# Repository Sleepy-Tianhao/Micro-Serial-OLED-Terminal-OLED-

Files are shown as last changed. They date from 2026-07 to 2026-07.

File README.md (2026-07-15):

# Micro Serial OLED Terminal (MSOT)  
> 嵌入式串口数据实时终端显示器 – 基于 Atmega328p + 0.96" OLED  

        

**Micro Serial OLED Terminal** 基于 Atmega328p 打造的轻量级串口数据显示终端，在 0.96 英寸屏幕上实时滚动显示串口ASCII 文本。支持一键 **暂停/恢复** 屏幕刷新，便于仔细查看历史数据，同时后台继续接收串口信息，恢复时即时补全。适用于嵌入式调试、传感器监控，**快速 & 便捷** 查看串口信息

---
# ⚙️ 特色功能
1. 配备有typec接口, **支持C to C数据线供电**, 支持由终端设备为调试设备供电,免去供电烦恼
2. 同时支持从调试设备取电, 即插即用
3. 支持**一键暂停**, 快速锁定内容
4. **跨平台换行兼容** – 支持 Windows (`\r\n`)、Linux (`\n`)、Mac (`\r`) 的换行风格。
5. **实时滚动显示** – 自动处理换行符（`\n` / `\r` / `\r\n`），实现平滑滚动，无撕裂或闪烁。

## 快速开始

>有关制作及其注意事项请详见此[文档](build.md)

### 外设
| 接口 | 功能 |
| :--- | :--- |
| USB-C | 仅供电, 兼容 C to C 数据线* |
| 4pin 排针 | 供电, 串口信号输入 |
| 拨轮 | 上拨向上翻页, 中键翻转刷新状态, 下拨向下翻页 |
| 蜂鸣器** | 按键提示 |

> *注: 须焊接R5 R6设为下拉以兼容 C to C数据线
  **注: 对应电路元件封装较小(0402封装), 不便于焊接, 此项为可选项

### 接线
| 4pin 排针(屏幕面从左到右) | 对外调试设备 |
| :--- | :--- |
| GND | GND |
| TXD | RXD |
| RXD | TXD |
| VCC | VCC / 5V |

## 🕹️ 使用说明  

### 基本操作  

| 操作 | 效果 |
| :--- | :--- |
| 串口发送文本（如 `Hello World\n`） | OLED 上滚动显示该行 |
| 发送超长文本（>21 字符） | 自动在 21 字符处换行 |
| 发送空行（单独 `\n`） | 产生一个空白行，用于间隔 |
| 按下中键 | 屏幕冻结，但串口继续接收 |
| 再次按下中键 | 屏幕立即补全所有新内容 |

### 软件环境
- **Arduino IDE** (≥1.8.13) 或 **PlatformIO**  
- 安装依赖库（通过 Arduino 库管理器）：  
  - `U8g2` by olikraus (≥2.28.10)  
  - `Adafruit BusIO`（U8g2 的依赖）

---

## 📦编译上传 
### 一. BootLoader烧录
1. 对于需 Arduino UNO / Nano 拆板的MCU可跳过此步骤, 移步至 **程序烧录** 步骤
2. 对于全新 Atmega328p 芯片: 
    1. 安装到编程座上, 或直接焊接至开发板上
    2. 使用AVRISP, 烧录BootLoader
       或使用另一块Arduino, 先上传Arduino ISP程序: *文件 --> 示例 --> ArduinoISP*, 然后按以下表格进行接线
    3. 点击 *工具 --> 编程器 --> Arduino as ISP (此项根据对应编程器选择, 此处以 Arduino as ISP 为例)*
    4. 点击 *烧录引导程序*

| 作为编程器的Arduino | 目标对象 |
| :--- | :--- |
| 13 | 13 |
| 12 | 12 |
| 11 | 11 |
| 10 | REST |
| GND | GND |
| VCC | VCC |

### 二. 程序烧录
>虽然PCB板已引出REST引脚, 但仍然建议先烧录程序, 再安装芯片到PCB板上
1. 下载位于src目录下的源码 `main.ino`。  
2. 在 Arduino IDE 中选择开发板 **Arduino Nano** 和对应串口。  
3. 点击 **上传**。  
4. 打开串口监视器（默认波特率 115200），发送任意文本，OLED 将立即滚动显示。

```shell
# 示例：发送 "Hello World\n"
# OLED 屏幕将显示该行，并自动换行滚动
```

---

## 开发指南

若你想在此基础上进行二次开发或定制，请遵循以下步骤：

```shell
git clone https://github.com/yourname/serial-oled-terminal.git
cd serial-oled-terminal/
# 使用 Arduino IDE 打开 main.ino，或使用 PlatformIO 打开项目文件夹
```

### 项目结构
```
├──PCB                       # PCB原始文件
├──BOM                       # 元件清单
├──Image                     # 示意图
├──Gerber                    # 制板文件
├──src
    └──  main.ino            # 主程序
├── README.md                # 本文件
└── LICENSE                  # MIT 许可证
```

### 核心代码模块
- **`processSerialData()`** – 非阻塞读取串口，解析 `\r`/`\n`，更新行缓冲区。  
- **`scrollUp()`** – 滚动显存数组（丢弃最旧行，为新行腾出空间）。  
- **`renderDisplay()`** – 使用 U8g2 全帧缓冲绘制并发送到 OLED。  
- **`handleButton()`** – 检测按钮下降沿，软件消抖，切换暂停状态。

## 🔧自定义配置
你可以在文件顶部修改以下宏定义以适应不同屏幕尺寸或硬件：

| 宏定义 | 默认值 | 说明 |
| :--- | :--- | :--- |
| `SCREEN_ROWS` | 6 | 显示行数（根据 OLED 高度和字体调整） |
| `SCREEN_COLS` / `MAX_LINE_LEN` | 21 | 每行字符数（根据 OLED 宽度和字体调整） |
| `BTN_PIN` | 2 | 按钮引脚号 |
| `DEBOUNCE_DELAY` | 50 | 消抖时间（毫秒） |

### 构建与测试
- 若更改了屏幕分辨率或字体，请同步调整 `SCREEN_ROWS` 和 `SCREEN_COLS`。  
- 编译时注意 RAM 占用（由于 ~硬件资源有限~ 个人能力不足, 当前已达94%）  
- 如需提升刷新速度，可在 `setup()` 中添加 `Wire.setClock(400000L);` 将 I2C 频率提至 400kHz。

### 配置参数

本项目提供了若干可调节的配置项，以适应不同硬件或偏好。

#### `SCREEN_ROWS`
- **类型**：`int`  
- **默认值**：`6`  
- **说明**：OLED 屏幕上显示的文字行数。根据屏幕高度和所选字体（当前为 6×10 像素）计算，例如 64 像素高度 / 10 像素行高 = 6 行。

#### `SCREEN_COLS`（同 `MAX_LINE_LEN`）
- **类型**：`int`  
- **默认值**：`21`  
- **说明**：每行最多容纳的字符数。根据屏幕宽度和字体宽度（6 像素）计算，128 / 6 ≈ 21。

#### `DEBOUNCE_DELAY`
- **类型**：`unsigned long`（毫秒）  
- **默认值**：`50`  
- **说明**：按钮消抖延时窗口。若按钮抖动较严重，可适当增大（如 100ms）。

#### 串口波特率
- **类型**：`long`  
- **默认值**：`115200`  
- **说明**：在 `Serial.begin()` 中修改。可与你的串口设备匹配（如 9600、57600 等）。

#### 示例：修改为 128×32 屏幕
若使用 128×32 分辨率 OLED，建议：
```cpp
#define SCREEN_ROWS     3
#define SCREEN_COLS     21
// 并在 setup() 中改用较小字体：u8g2.setFont(u8g2_font_5x7_tf);
```

---

## 贡献指南

由于此项目为我个人第一个正式开源项目, 且我个人能力十分有限, BUG在所难免. 所以欢迎任何形式的贡献，无论是问题报告、功能建议还是代码提交。请遵循以下流程：

1. **Fork** 本仓库到你的 GitHub 账户。  
2. 创建一个新的 **功能分支**（`git checkout -b feature/amazing-feature`）。  
3. 提交你的修改（`git commit -m 'Add some amazing feature'`）。  
4. 推送到分支（`git push origin feature/amazing-feature`）。  
5. 打开一个 **Pull Request**，清晰描述你的更改内容

---

## 链接与资源

- **项目主页**： [https://github.com/Sleepy-Tianhao/Micro-Serial-OLED-Terminal-OLED-](https://github.com/Sleepy-Tianhao/Micro-Serial-OLED-Terminal-OLED-)  
- **源代码仓库**： [https://github.com/Sleepy-Tianhao/Micro-Serial-OLED-Terminal-OLED-](https://github.com/Sleepy-Tianhao/Micro-Serial-OLED-Terminal-OLED-)  
- **问题跟踪**： [https://github.com/Sleepy-Tianhao/Micro-Serial-OLED-Terminal-OLED-/issues](https://github.com/Sleepy-Tianhao/Micro-Serial-OLED-Terminal-OLED-/issues)  
- **相关项目**：  
  - [U8g2 图形库](https://github.com/olikraus/U8g2_Arduino) – 为本项目提供 OLED 驱动。  
  - [Arduino 官方文档](https://www.arduino.cc/reference/en/) – 参考 Arduino API。

**联系**：如有疑问，可以发送邮件至 `bilibili.dragon.boy@gmail.com`。

---

## 许可证

本项目采用 **MIT 许可证**，详情请参阅 [LICENSE](LICENSE) 文件。  

---

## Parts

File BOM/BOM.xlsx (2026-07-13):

No. | Quantity | Comment | Designator | Footprint | Value | Manufacturer Part | Manufacturer | Supplier Part | Supplier
1 | 1 | 4kHz | BUZZER1 | BUZ-SMD_L5.0-W5.5-P4.60 | 4kHz | MLT-5020 | 华能 | C94598 | LCSC
2 | 2 | 22pF | C1,C2 | C0603 | 22pF | CL10C220JB8NNNC | SAMSUNG(三星) | C1653 | LCSC
3 | 5 | 100nF | C3,C4,C5,C6,C7 | C0603 | 100nF | FCC0603B104K500CT | FOJAN(富捷) | C5137636 | LCSC
4 | 1 | 1N4148WT | D1 | SOD-523_L1.2-W0.8-LS1.6-FD |  | 1N4148WT | CJ(江苏长电/长晶) | C2961218 | LCSC
5 | 1 | A254UP-ZD04P | H1 | HDR-TH_A254UP-ZD04P |  | A254UP-ZD04P | BXCONN(宝讯) | C41413833 | LCSC
6 | 1 | 2SC5658 | Q1 | SOT-723_L1.2-W0.8-P0.80-LS1.2-BR |  | 2SC5658 | CJ(江苏长电/长晶) | C2991944 | LCSC
7 | 5 | 5.1kΩ | R1,R2,R3,R5,R6 | R0603 | 5.1kΩ | FRC0603F5101TS | FOJAN(富捷) | C2907044 | LCSC
8 | 1 | 1K | R4 | R0402_无丝印
9 | 1 | 10K | R16 | R0402_无丝印
10 | 1 | Test-Point | RST | Test-Point-0.5mm
11 | 1 | ATMEGA328P-AU | U1 | TQFP-32_L7.0-W7.0-P0.80-LS9.0-BL |  | ATMEGA328P-AU | MICROCHIP(美国微芯) | C14877 | LCSC
12 | 1 | HS96L03W2C03 | U2 | OLED-TH_L27.8-W27.2-P2.54_C9900033791 |  | HS96L03W2C03 | HS(汉昇) | C5248080 | LCSC
13 | 1 | BL-DT | U3 | SW-SMD_BL-DT |  | BL-DT | SHOU HAN(首韩) | C53223909 | LCSC
14 | 1 | TYPE-C 6P | USB1 | TYPE-C-SMD_TYPE-C-6P_1 |  | TYPE-C 6P | SHOU HAN(首韩) | C456012 | LCSC
15 | 1 | 16MHz | X1 | CRYSTAL-SMD_4P-L3.2-W2.5-BL | 16MHz | X322516MLB4SI | YXC(扬兴晶振) | C13738 | LCSC
16 | 1 | A2541WR-4P | H1 | A2541WR-4P
17 | 4 | M2 Hexagonal Copper Standoff |  | M2*4+3
18 | 4 | M2 Screw |  | M2*3
19 | 4 | M2 Nut |  | M2

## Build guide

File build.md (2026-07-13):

# 制作说明

> 元件清单详见BOM/BOM.xlsx

## 一. 焊接 & 组装 顺序
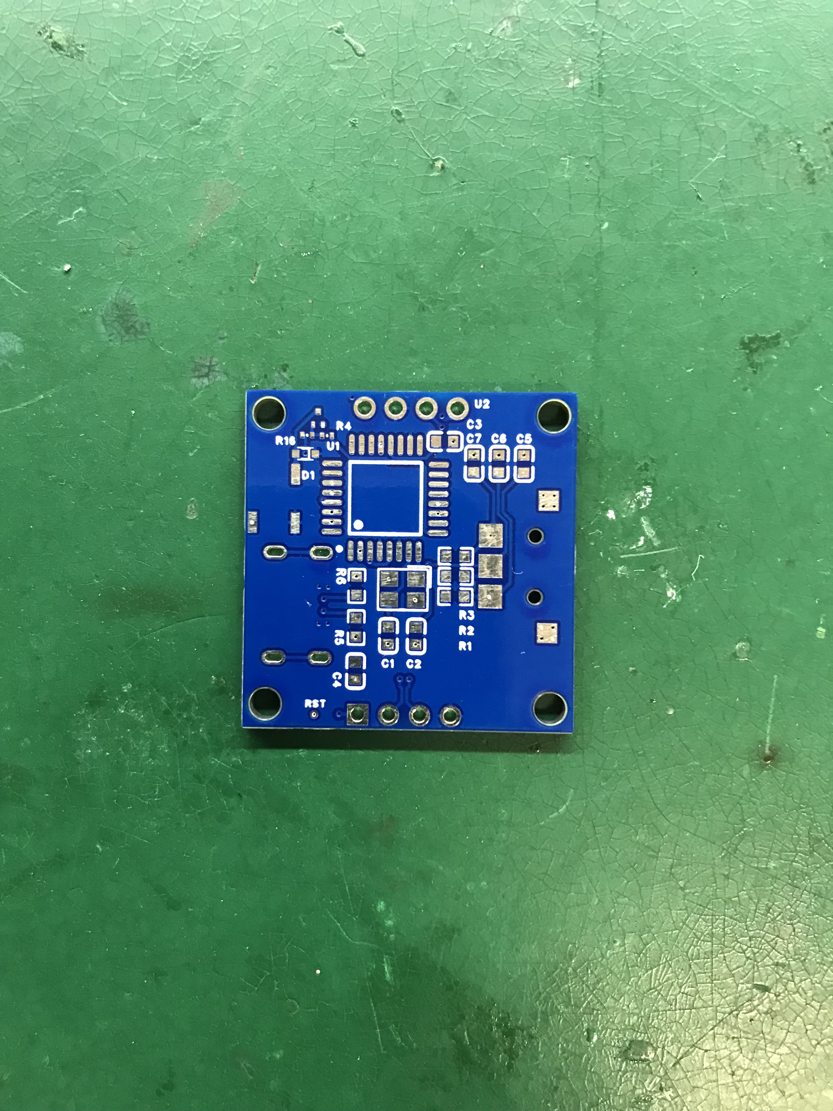
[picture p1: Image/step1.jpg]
步骤1

1. 先焊接上表面元件: *电阻 --> 电容 --> 晶体振荡器 --> 三极管(可选) --> 蜂鸣器(可选) --> 拨轮开关 --> 4pin弯角排针*
2. 检查焊接质量, 测量供电部分是否阻值异常
3. 焊接主IC芯片
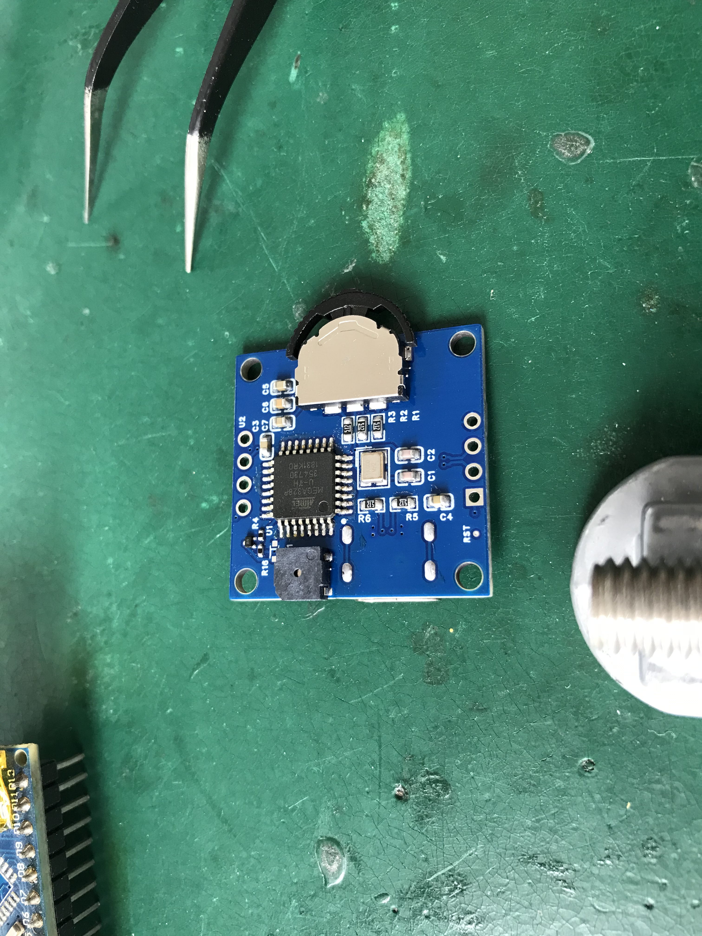
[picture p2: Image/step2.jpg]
步骤2

> 以上焊接步骤建议统一使用 **加热台 + 锡膏** 焊接,  可一步到位
  IC芯片默认为已烧录好全部程序 **强烈建议先烧录程序**
4. 翻至反面, 焊接USB-C接口 (建议使用**电烙铁**拖焊)
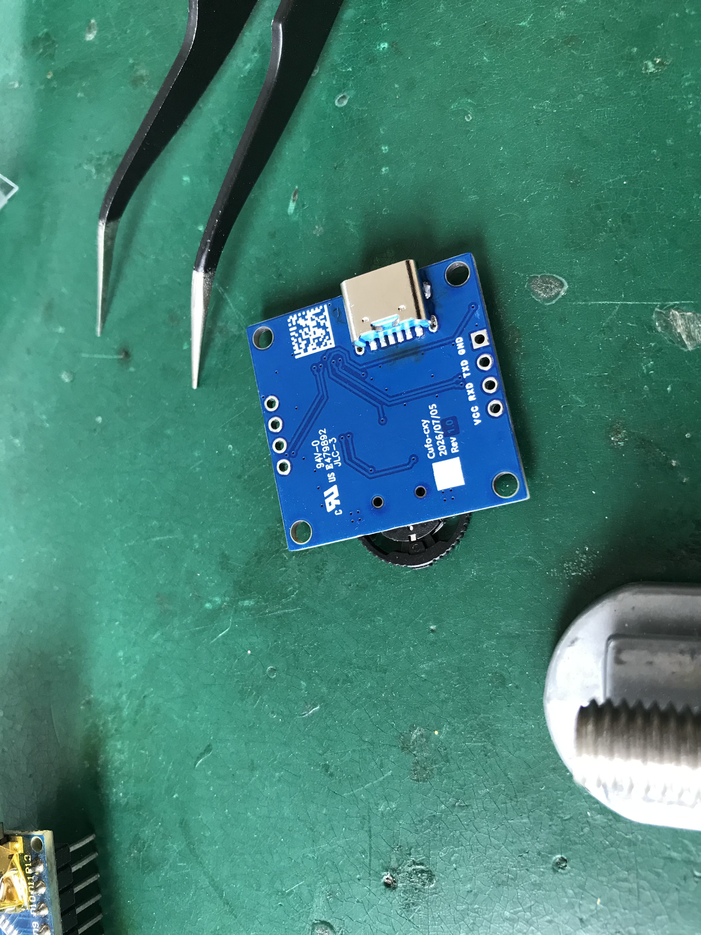
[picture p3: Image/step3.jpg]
步骤3

5. 确认无短路等问题后, 先尝试通过USB-C口供电, 使用万用表等工具检查供电情况. 
> 对于焊接了蜂鸣器的用户, 此时可以通过上下拨动开关, 观察蜂鸣器是否正常工作, 以初步判断主芯片是否工作正常
6. 确认正常工作后, 先固定四角螺柱 **注意! 不要拧的太死, 以防止损坏上下阻焊层而导致供电短路!!!** ~我就是这样烧掉了一块~
7. 先将oled屏幕模块通过M2螺丝固定, 再在PCB反面进行焊接

## 二. 测试 & 完工
1. 通过 4pin 排针供电, 并连接TTL串口模块, ***~然后 3, 2, 1, 起爆!~***
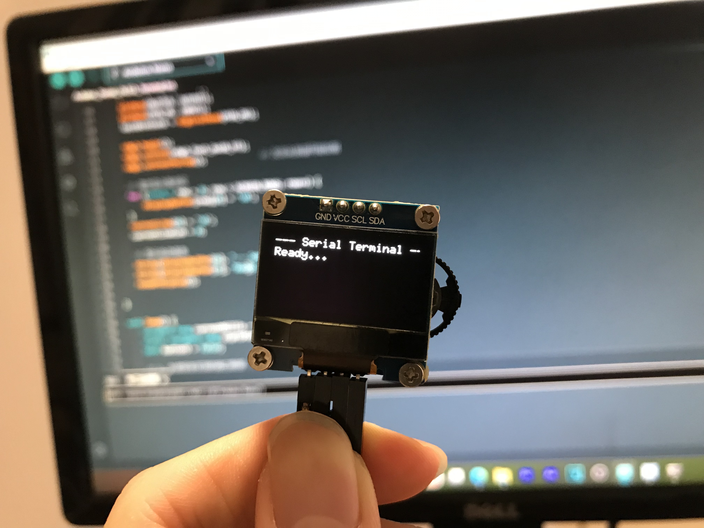
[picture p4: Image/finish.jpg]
完工!

2. 打开电脑上的串口调试程序, 或使用 Arduino IDE 自带的串口调试, 发送几段内容

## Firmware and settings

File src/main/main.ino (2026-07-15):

/*
  Arduino UNO + OLED 串口终端显示器
  功能：读取串口数据，实时滚动显示在 OLED 屏幕上
 */
#include <Arduino.h>
#include <U8g2lib.h>
#define BUZZER  5
#define PIN_DOWN  8
#define PIN_UP  7
#define PIN_OK  4

U8G2_SSD1306_128X64_NONAME_F_HW_I2C u8g2(U8G2_R0, /* reset=*/ U8X8_PIN_NONE);

#define SCREEN_ROWS     6
#define SCREEN_COLS     21     // 每行最大字符数（根据字体调整）
#define MAX_LINE_LEN    SCREEN_COLS

// 行缓冲区：存储当前屏幕上的所有行文本
char displayBuffer[SCREEN_ROWS][MAX_LINE_LEN + 1];

// 当前正在构建的行（尚未换行）
char currentLine[MAX_LINE_LEN + 1];
uint8_t currentLineLen = 0;

unsigned long previousMillis = 0;
const long interval = 100;
bool refreshPaused = false;
unsigned long lastBtnTime = 0;
const unsigned long debounceDelay = 50;
int lastBtnState = HIGH;

// 标记是否需要刷新屏幕
bool needRefresh = false;

void addCharToDisplay(char c);
void scrollUp(void);
void renderDisplay(void);
void processSerialData(void);
void pause(void);

void setup() {
    Serial.begin(115200);
    
    pinMode(PIN_DOWN, INPUT);
    pinMode(PIN_UP, INPUT);
    pinMode(BUZZER, OUTPUT);
    pinMode(PIN_OK, INPUT);
    lastBtnState = digitalRead(PIN_OK);

    u8g2.begin();
    u8g2.setFont(u8g2_font_6x10_tf);
    u8g2.setFontPosTop();              // 文字从顶部开始绘制
    
    // 清空显示缓冲区
    for (uint8_t row = 0; row < SCREEN_ROWS; row++) {
        displayBuffer[row][0] = '\0';
    }
    currentLine[0] = '\0';
    currentLineLen = 0;

    // 显示启动信息
    strcpy(displayBuffer[0], "--- Serial Terminal ---");
    strcpy(displayBuffer[1], "Ready...");
    renderDisplay();
    
}

void loop() {
    unsigned long currentMillis = millis();
    static unsigned long startPressed3 = 0;   
    bool button3 = false;

    // 1. 处理所有可用的串口数据
    processSerialData();
    rollUp();
    rollDown();
    pause();
    
    // 2. 如果有数据更新，且处于刷新状态时,刷新屏幕
    if (!refreshPaused && needRefresh) {
        renderDisplay();
        needRefresh = false;
    }

    if(digitalRead(PIN_OK) == LOW){
    unsigned long timeReleased3 = millis() - startPressed3;
    if(timeReleased3 < 1000 && timeReleased3 > 10){
      button3 = true;
      if(button3 == true){
      needRefresh = true;
      button3 = false;
      tone(BUZZER, 4000);
      startPressed3 = millis() - 1000;
      }
    }else{
      button3 = false;
    }
  }else{
     startPressed3 = millis();
  }

    if (currentMillis - previousMillis >= interval) {
        previousMillis = currentMillis;
        noTone(BUZZER);
    }
    //微小延时，用以充分利用cpu资源
    delay(1);
}

//处理串口数据
void processSerialData() {
    while (Serial.available() > 0) {
        char c = Serial.read();
        
        // 处理换行符
        if (c == '\n' || c == '\r') {
            // 如果当前行有内容，或者收到的是单独的换行符（空行）
            if (currentLineLen > 0 || c == '\n') {
                // 将当前行加入显示缓冲区（滚动）
                scrollUp();
                strcpy(displayBuffer[SCREEN_ROWS - 1], currentLine);
                // 清空当前行
                currentLine[0] = '\0';
                currentLineLen = 0;
                needRefresh = true;
            }
            // 如果是 \r，忽略（不产生空行）
            // 如果是 \n，且当前行为空，产生一个空行
            if (c == '\n' && currentLineLen == 0) {

            }
        } else {
            // 普通字符：追加到当前行
            addCharToDisplay(c);
        }
    }
}

//添加字符到当前行
void addCharToDisplay(char c) {
    // 忽略不可打印字符（除了空格）
    if (c < 32 && c != ' ') return;
    
    // 如果当前行已满，直接换行
    if (currentLineLen >= MAX_LINE_LEN) {
        // 将当前行加入显示缓冲区
        scrollUp();
        strcpy(displayBuffer[SCREEN_ROWS - 1], currentLine);
        currentLine[0] = '\0';
        currentLineLen = 0;
        needRefresh = true;
    }
    
    // 追加字符
    currentLine[currentLineLen] = c;
    currentLineLen++;
    currentLine[currentLineLen] = '\0';
    needRefresh = true;
}

//屏幕滚动（所有行上移一行）
void scrollUp() {
    // 将第 1~5 行移动到第 0~4 行
    for (int row = 0; row < SCREEN_ROWS - 1; row++) {
        strcpy(displayBuffer[row], displayBuffer[row + 1]);
    }
    // 最后一行清空
    displayBuffer[SCREEN_ROWS - 1][0] = '\0';
}

//屏幕滚动（所有行下移一行）
void scrollDown() {
  // 将第 0~4 行移动到第 1~5 行
    for (int row = SCREEN_ROWS - 2; row >= 0; row--) {
        strcpy(displayBuffer[row + 1], displayBuffer[row]);
    }
    displayBuffer[0][0] = '\0';
}

//渲染 OLED 屏幕
void renderDisplay() {
    u8g2.clearBuffer();  // 清空
    
    //绘制
    for (uint8_t row = 0; row < SCREEN_ROWS; row++) {
        // 计算 Y 坐标：行号 * 字体高度(10)
        uint8_t y = row * 10;
        u8g2.drawStr(0, y, displayBuffer[row]);
    }
    
    u8g2.sendBuffer();  // 将内容发送到屏幕
}

//手动上移显示
void rollUp() {
   static unsigned long startPressed2 = 0;   
   bool button2 = false;
  if(digitalRead(PIN_UP) == LOW){
    unsigned long timeReleased2 = millis() - startPressed2;
    if(timeReleased2 < 1000 && timeReleased2 > 10){
      button2 = true;
      if(button2 == true){
      scrollUp();
      currentLine[0] = '\0';
      needRefresh = true;
      button2 = false;
      tone(BUZZER, 4000);
      startPressed2 = millis() - 1000;
      }
    }else{
      button2 = false;
    }
  }else{
     startPressed2 = millis();
  } 
}

//手动下移显示
void rollDown() {
   static unsigned long startPressed1 = 0;    
   bool button1 = false;
  if(digitalRead(PIN_DOWN) == LOW){
    unsigned long timeReleased1 = millis() - startPressed1;
    if(timeReleased1 < 1000 && timeReleased1 > 10){
      button1 = true;
      if(button1 == true){
      scrollDown();
      currentLine[0] = '\0';
      needRefresh = true;
      button1 = false;
      tone(BUZZER, 4000);
      startPressed1 = millis() - 1000;
      }
    }else{
      button1 = false;
    }
  }else{
     startPressed1 = millis();
  } 
}

void pause() {
    int currentState = digitalRead(PIN_OK);
    
    if (currentState == LOW && lastBtnState == HIGH) {
        if (millis() - lastBtnTime > debounceDelay) {
            refreshPaused = !refreshPaused;   // 切换暂停状态
            lastBtnTime = millis();
            needRefresh = true;
            }
        }
      lastBtnState = currentState;
    }
